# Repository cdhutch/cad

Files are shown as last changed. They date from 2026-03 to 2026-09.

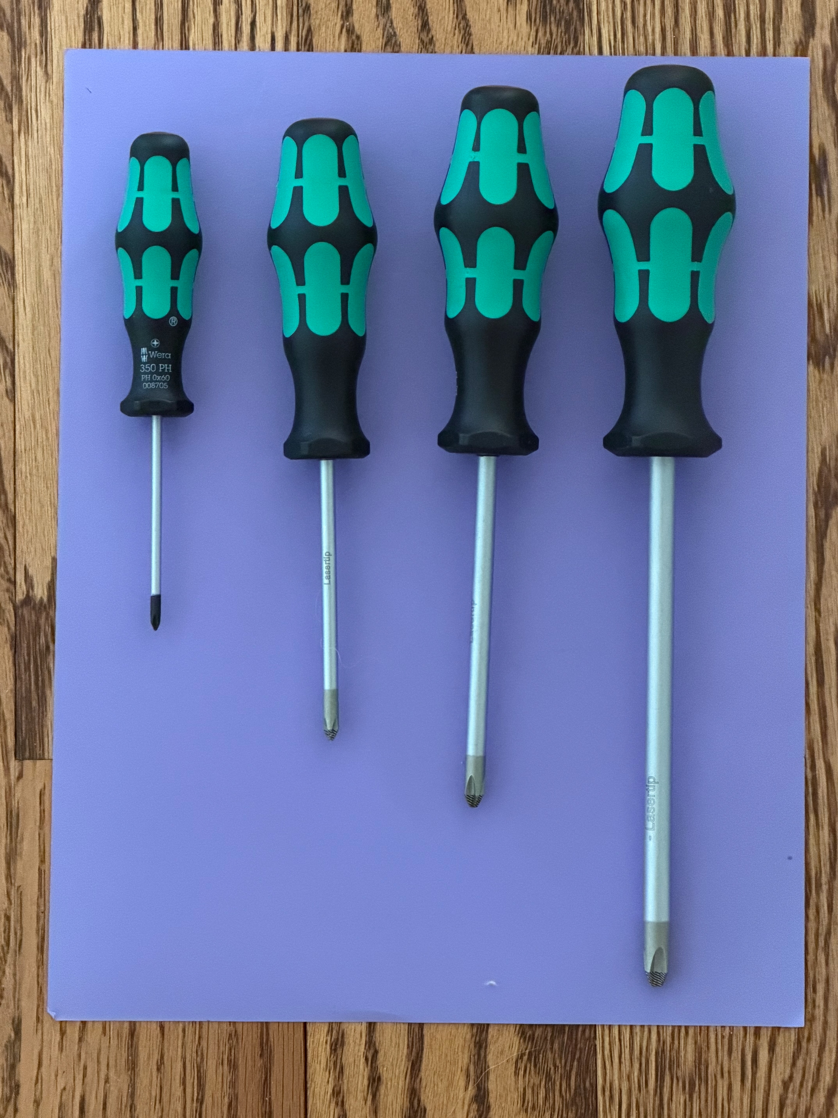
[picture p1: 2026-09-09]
gridfinity/source/tooltrace/wera-phillips-flathead-screwdrivers/photos/phillips.jpeg

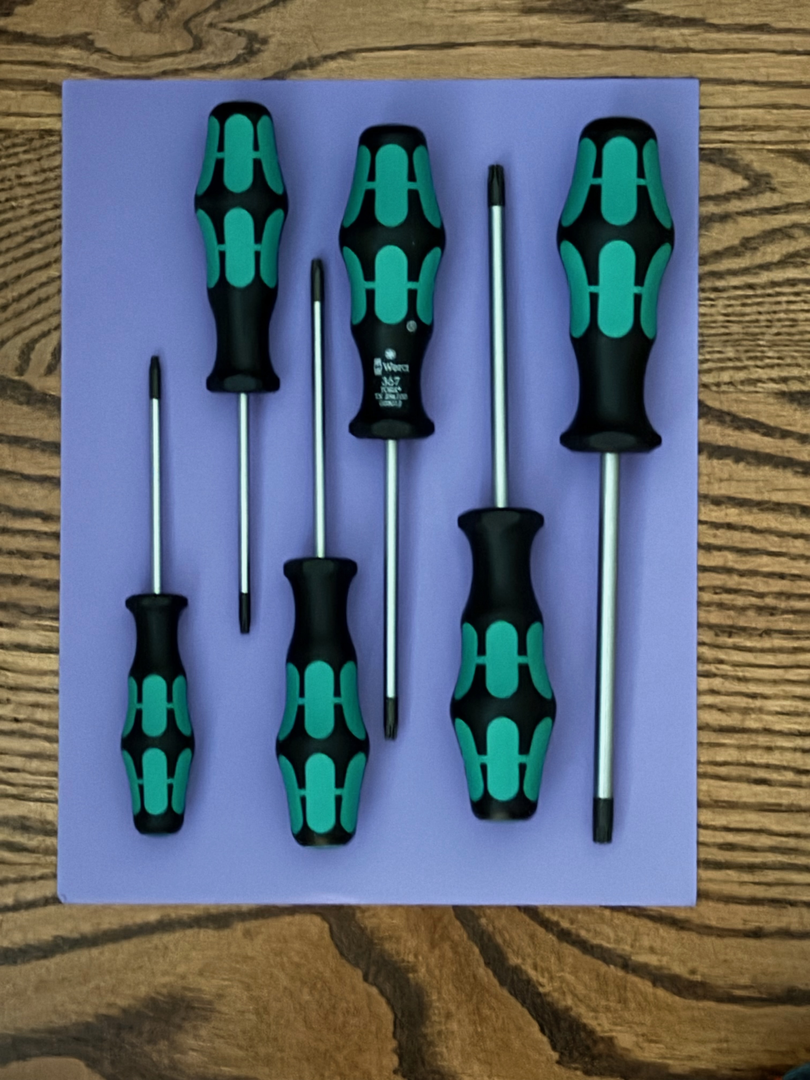
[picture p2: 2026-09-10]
gridfinity/source/tooltrace/wera-367-6-torx/photos/torx.jpeg

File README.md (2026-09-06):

# CAD Library

A general repository for CAD models and 3D-printing assets.

This repository stores parametric design references, exported geometry,
and slicer projects used for prototyping, shop organization, and
hardware builds.

For the fuller working context (active branch, per-project inventory,
step-by-step workflow) see `CLAUDE.md`.

## Design Workflow (summary)

1. **tooltrace.ai** — photograph a tool to extract its 2D/3D profile (STEP + DXF)
2. **Onshape** — import the profile, subtract it from a Gridfinity tray body
3. **Export** — STL for remixing, `.3mf` slicer projects (Bambu Studio) for printing

## Repository Structure

    cad/
    ├── README.md
    ├── CLAUDE.md
    ├── docs/
    │   └── repo-conventions.md
    └── gridfinity/
        ├── README.md
        ├── docs/
        │   ├── naming.md
        │   ├── notes.md
        │   ├── allen-wrench-tray.md
        │   ├── wera-electrical-screwdrivers-tray.md
        │   └── drill_tray_generator.md
        ├── source/
        │   ├── onshape/
        │   │   └── links.md
        │   ├── step/
        │   │   ├── allen-wrenches/
        │   │   └── wera-electrical-screwdrivers/
        │   └── tooltrace/
        │       ├── allen-wrenches/
        │       └── wera-electrical-screwdrivers/
        ├── stl/
        │   ├── baseplates/
        │   │   └── magnet/
        │   └── inserts/
        │       ├── allen-wrenches/
        │       └── wera-electrical-screwdrivers/
        └── 3mf/
            ├── baseplates/
            │   └── magnet/
            ├── grids/
            ├── allen-wrenches/
            ├── nystrom_performance/
            └── wera-electrical-screwdrivers/

## Directory Purpose

### `docs/`

General documentation for the CAD repository: repo conventions, naming
rules, organizational guidance.

### `gridfinity/`

Gridfinity-compatible storage designs and experiments.

#### `source/`

Editable or reference CAD information: Onshape document links, STEP
exports for interoperability, and raw tooltrace.ai exports (STL + DXF)
kept as reference/import material.

#### `stl/`

Printable mesh geometry exported from CAD, split into `baseplates/`
(generic Gridfinity infrastructure) and `inserts/` (tool-specific trays).

#### `3mf/`

Slicer project files (Bambu Studio builds) — plate layouts, supports,
print profiles, often multiple parts per build. Subdirectories organize
prints by role or project, e.g. `baseplates/`, `grids/`, `nystrom_performance/`.

#### `docs/`

Project-specific notes, naming conventions, and per-tool design write-ups.

## File Type Conventions

Preferred formats and naming rules are defined in `docs/repo-conventions.md`
and, for Gridfinity specifics, `gridfinity/docs/naming.md`. In short:
lowercase, hyphenated, version-suffixed filenames; `.3mf`/`.stl`/`.step`/`.stp`/`.dxf`,
all tracked via Git LFS.

## Included Systems

Currently includes:

- Gridfinity storage components (baseplates, grids)
- Drawer organization trays (Nystrom Performance cabinet)
- Custom tool-specific inserts (Allen wrenches, Wera screwdrivers)

Additional CAD projects may be added as new top-level folders alongside
`gridfinity/`, following `docs/repo-conventions.md`.

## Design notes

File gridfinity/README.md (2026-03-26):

# Gridfinity STL Library

Organized Gridfinity-compatible STLs:
- `stl/base/` baseplates/grids/foundations
- `stl/inserts/` tool- and use-specific inserts

See `docs/naming.md` for file naming conventions.

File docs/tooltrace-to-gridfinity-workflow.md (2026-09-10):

# Tool-Specific Gridfinity Tray Workflow (ToolTrace → Gridfinity)

A reproducible, step-by-step guide to building exact-fit tool pockets (Allen
wrenches, screwdrivers, anything with an irregular silhouette).

**Default path: ToolTrace's own native "Gridfinity" export** (Part 1 below)
— trace, lay out, and export STEP/STL directly from ToolTrace, with no CAD
step in between. Use this unless your layout needs something ToolTrace's
manual drag/rotate Layout canvas can't do — namely a **tight interlocking
nest** that packs irregular shapes tighter than simple non-overlapping grid
placement, to minimize wasted Gridfinity squares. For that case, fall back
to the Onshape path (Part 2).

Written up while building the Wera 454/7 HF Set 1 tray
(`gridfinity/docs/wera-454-7-hf-set-1-tray.md`) — that doc has this
project's specific numbers; this doc is the general procedure.

---

## Part 1: ToolTrace-native path (default)

### 1. Photograph the tools

- Shoot on a plain, high-contrast, colored background (cleaner trace than
  paper/white) or on one sheet of Letter/A4 paper with all 4 corners
  visible if you need ToolTrace's paper-based scale calibration instead.
- Multiple tools can share one photo, but every tool must be fully
  separated from the others — no touching/overlapping outlines, and no
  tool touching the edge of the page/background (a trace touching the edge
  can fuse into the background boundary).
- Shoot from further away and zoom in (physically or in-camera) rather than
  filling the frame at close range — reduces lens distortion at the edges
  of the photo, which otherwise skews the traced outline.
- Even, shadow-free lighting — a cast shadow next to the tool can get
  traced as part of its silhouette.
- Include a calibration reference (ruler, checkerboard, or known-size
  object) in frame for ToolTrace's corner-calibration step.
- Export/save as **JPEG or PNG** — ToolTrace's HEIC decoding is unreliable
  server-side ("Failed to convert HEIC file"); convert HEIC photos first.

### 2. Measure/verify tool dimensions independently

Don't rely on the trace alone for critical dimensions — cross-check against
the manufacturer's datasheet and/or physical measurement:
- Watch for spec ambiguity (e.g. Wera's "10.0×200" is the *shaft* length
  only; the handle block adds on top of it — total tool length ≈ shaft +
  handle).
- A single WebFetch of a retailer product page can garble tables (columns
  merging, e.g. a "qty: 1" column bleeding into a size column) — if numbers
  look suspicious, fetch the manufacturer's PDF datasheet directly and
  cross-check.

### 3. Trace each photo in ToolTrace

- One photo = one ToolTrace session/design; there's no multi-photo upload
  into a single session.
- **Mode: Fast vs. Detail** — set this before adding any tool; it cannot be
  changed on a tool after it's added (changing it loses the tool and it
  must be re-added).
  - **Detail mode** segments by apparent contiguous color/material region.
    On a multi-material tool (e.g. matte handle + shiny metal shaft) this
    fragments the tool into multiple disconnected pieces instead of one
    outline.
  - **Fast mode** grabs the whole tool silhouette in a single click. Less
    precise on fine contour detail, but doesn't fragment multi-material
    tools. **Use Fast mode for tools with a handle + metal shaft**
    (T-handles, screwdrivers, etc.).
- Rename the session immediately (the `Name` field) — default names are
  generic/auto-generated and easy to confuse with leftover sessions from
  earlier work.
- Click each tool to trace it, name it, and — critically — **click OK to
  confirm the trace**. A trace that is never confirmed with OK does not
  persist: reopening the design will show the bare photo with no
  AI-selected tool, and the tool will not appear in Import Traces from
  other designs.

### 4. Fix bad traces with Fine Tune

If an exported STEP/STL later comes out looking inverted or corrupted, go
back to the Layout step's **Fine Tune** tool and manually smooth the
offending outline. A hand-traced curve can contain a "sketch singularity"
— a self-intersecting loop or an acute/degenerate point — that blows up
the boolean subtraction used to generate the pocket, producing a solid
tool-shaped plug instead of a recessed pocket. Fine Tune lets you clean up
the outline without re-tracing from scratch.

ToolTrace's Fine Tune UI is good at surfacing exactly where a singularity
is on a given outline — worth checking there proactively (before export)
rather than only reactively after a bad STEP/STL turns up.

### 5. Combine traces from multiple designs with Import Traces

- If your tools are spread across several photos/designs, open the design
  you want to build the final tray in and use **Import Traces** (button
  labeled "Import Tools") to pull in already-traced, OK-confirmed tools
  from your other ToolTrace designs.
- Imported tools show `Source: Imported` in their tool popup (Mode/Enforce
  Symmetry/Angle aren't shown — those only apply at trace time — but
  Pocket Depth remains editable). A generic "Imported" placeholder instead
  of a live thumbnail appears to be cosmetic, not a failed import.
- **Gotchas:**
  - Leftover/stray sessions from past work can appear in the import picker
    under similarly generic auto-generated names — double-check
    thumbnails/dates before selecting, to avoid importing a duplicate.
  - Clicking a tool's **×** in the Tools panel deletes it immediately with
    no confirmation. If this happens by accident, re-import it via Import
    Traces from its original session rather than re-tracing.

### 6. Lay out the tools

- Arrange all tools in the workspace with no overlap. Freshly
  imported/added tools may all appear superimposed at first — drag them
  apart manually.
- ToolTrace's Layout canvas is **manual drag/rotate only** — no auto-nest
  or auto-arrange. It snaps to the grid and shows live size feedback (mm).
  This is fine for "arrange without overlap"; it is **not** the tool for a
  tight interlocking nest that minimizes wasted grid squares — for that,
  use the Onshape path (Part 2) instead.
- Use **Add Simple Shapes → Finger Notch** to add a finger-access scallop
  to any pocket you'll need to pinch a tool out of: a circle with a live,
  draggable diameter. Position it straddling the edge of the pocket. Set
  its depth **deeper than the pocket it's attached to** (retrieval is
  handled by the notch reaching below the tool, not by the pocket itself).
- Other shapes here (Circle, Square, Rectangle, Rounded Rect, Text) are for
  labels/general cutouts, not tool-specific.

### 7. Size and export in the Design step

- **Pocket Depth** (per tool, via each tool's popup) — set individually.
  Rule of thumb: ≈70% of the tool's own handle/crossbar thickness (not the
  hex bit or fastener diameter), leaving ≥2–3mm of base material below the
  pocket floor.
- **Customize Overall Size → Grid Length/Grid Width** — tray footprint in
  Gridfinity grid units (1 unit = 42mm). Pick even numbers so a grid cell
  isn't split across a design boundary — though it would still print fine.
- **Custom Grid Size** — set to **42mm** for standard Gridfinity pitch.
- **Split for Multiple Prints** — subdivides a layout larger than your
  printer's bed into multiple plates, each no larger than a size you
  specify (e.g. 252×252mm = 6×6 units). If a tool's pocket exceeds one
  plate, ToolTrace deliberately splits it across the shared edge of two
  adjacent plates — intentional, not a bug: the pocket halves align once
  the printed plates sit next to each other.
- **Puzzle Piece Mode** (GRIDFINITY panel) — trims empty grid cells so the
  printed outline hugs the tool shapes instead of a full rectangle.
  Separate from, and combinable with, Split for Multiple Prints.
- **Lip Design** (Default/None) and **Base magnets** (None/Corner/Full) —
  standard Gridfinity bin-bottom options.
- **Type must stay "Gridfinity"**, not "Foam" — Foam mode is believed to
  export a solid cutter/tool-shaped body rather than a tray with a
  recessed pocket; check this first if an export ever looks inverted.
- Export **STEP and/or STL**. STEP exports the whole design as one file
  (not split per plate — the plate split is a print-file concept). For a
  split layout, the STL export is a ZIP containing one **tray** STL + one
  **inserts** STL per plate, plus a `manifest.json` with each plate's
  position/size. **Only the tray STL is printed** — load one tray STL per
  plate into Bambu Studio, one print job at a time; the inserts file isn't
  sent to the printer.

### 8. Verify before printing

ToolTrace's own in-browser 3D preview can be unreliable to read — it has
been observed rendering one view for a few seconds and switching to
another, and pocket depths can look visually deceptive (a very deep value
on one tool makes every other tool look shallow by comparison). For a
trustworthy check, load the exported STEP/STL into Bambu Studio (or
Onshape) and inspect it there directly.

### 9. Slice and print

1. Import the STL(s) into Bambu Studio.
2. Use the **"Gridfinity Tray - Light"** process preset
   (`gridfinity/docs/gridfinity-tray-light.json` /
   `gridfinity/docs/bambu-tool-tray-profile.md`) — tuned for low-strength,
   gravity-load-only tool trays: minimal infill, fast print, no brim.
3. Save the sliced **project** as `.3mf` (not "export sliced file" — that
   embeds gcode and bloats the file) →
   `gridfinity/3mf/<project-name>/<descriptive-name>_v<n>.3mf`.
4. Archive source files: STEP/STL/photos under
   `gridfinity/source/tooltrace/<project-name>/` and
   `gridfinity/source/step/<project-name>/` (Git LFS tracks `*.stl`,
   `*.3mf`, `*.step`, `*.stp`, `*.dxf`).
5. Print, test-fit, and update the project doc's Status checklist.

---

## Part 2: Onshape path (fallback / advanced)

Use this instead of Part 1 only when you need a **tight interlocking nest**
that packs irregular tool shapes tighter than simple non-overlapping grid
placement (minimizing total Gridfinity squares consumed across however many
plates are needed), or when ToolTrace's native export produces geometry you
need to hand-repair in real CAD.

**Known reliability risk:** DXF import into Onshape has repeatedly dropped
or corrupted tool geometry on this repo's projects — a tool trace touching
the edge of its source photo/paper gets fused with the page boundary into
one degenerate closed loop that isn't cleanly separable back into a usable
outline (confirmed via DXF entity/geometry analysis with Python `ezdxf`).
This is why the Wera 454/7 HF Set 1 tray was rebuilt on the Part 1 path
after starting here. If you hit this, prefer the STL fallback procedure
below over DXF, or switch to Part 1 entirely if your layout doesn't
actually need interlocking nesting.

### Steps

1. **Trace each photo in ToolTrace** — same as Part 1, steps 1–3, but you
   only need clean individual tool outlines; you don't need to combine,
   lay out, or export a finished design from ToolTrace at all.
2. **Export from ToolTrace: Download → STEP** (also available: SVG, DXF,
   STL, 3MF, PDF).
   - The export contains one solid per tool **plus an auto-generated
     baseplate/background solid** sized to the layout's bounding box —
     discard that extra solid in CAD.
   - Tool solids are thin (~0.5mm) flat "stamp" extrusions — 2D profiles
     meant to be re-extruded to your chosen pocket depth in CAD, not
     pre-cut cavities.
   - Archive the STEP under
     `gridfinity/source/step/<project-name>/<descriptive-name>_v<n>.step`.
3. **Import into Onshape**: new/existing Part Studio → discard the
   auto-generated baseplate solid → clean up each tool profile (trim any
   shadow-elongated edges back to the true silhouette; verify dimensions
   against your independently-measured values from step 2 of Part 1 —
   traced bounding boxes can retain a slight rotation from the source
   photo angle).
4. **Nest** the cleaned profiles at exact coordinates, respecting your
   printer's practical build-plate cap in Gridfinity units (e.g. a
   256mm-cube printer → 6×6 grid units = 252×252mm per plate). Group tools
   into multiple plates if needed and note the split.
5. **Extrude** a Gridfinity tray body per plate and **boolean-subtract**
   the tool pockets + finger notches.
6. Apply the **standard Gridfinity bin-bottom interface** (lip, 42mm grid,
   optional magnet pockets) — use the repo's usual approach (custom
   feature or generator) rather than hand-modeling it.
7. **Export STL** per plate → `gridfinity/stl/inserts/<project-name>/`.
8. Record the Onshape document link in `gridfinity/source/onshape/links.md`.
9. Slice and print — same as Part 1, step 9.

### STEP import can hang forever — STL fallback procedure

STEP import into Onshape can get stuck at **"Post-processing..."**
indefinitely (not just slow) for a given file — confirmed by two separate
full-import attempts (default "Import to this document" mode, then
"Combine to a single Part Studio" mode) that both stalled identically for
10+ minutes, with Onshape's own status page showing "All Systems
Operational" at the time. If a STEP import is still stuck after several
minutes, cancel and fall back to STL:

1. **Export STL instead of STEP** from ToolTrace (Download → STL). This
   zips **one file per solid body** (`body_1.stl`, `body_2.stl`, ... one
   per tool, plus one for the auto-generated baseplate). Discard the
   baseplate STL (largest file by far).
2. **Upload all the tool STLs to Onshape in one batch** (drag/drop or the
   file picker takes multiple files at once).
3. In the **Units** dropdown of the import dialog, change it to
   **Millimeter** — Onshape's STL importer defaults to Inch, so ToolTrace's
   mm-based exports come in 25.4× oversized otherwise. (Shortcut: focus the
   dropdown and press "m" twice — first press selects Meter, second
   cycles to Millimeter.) Leave "Create a composite part when importing
   multiple or non-solid bodies" unchecked if you want each tool as an
   independently-positionable part later.
4. Unlike STEP import, the STL import dialog has no "combine to a single
   Part Studio" option — each STL becomes its own Part Studio tab, plus one
   extra raw "CAD Imports" tab. Consolidate them yourself (next step).
5. **Consolidate into one working Part Studio using the "Derived" feature**
   (Search Tools → "derive", not on the default toolbar): in your target
   Part Studio, Search Tools → Derived → "Select Part Studio..." → pick a
   source tab → confirm. Repeat once per source tab.
   - **Copy/paste of parts between Part Studio tabs is unreliable** in this
     workflow — use Derived instead.
   - On a Mac, use **Cmd+click** (not Ctrl+click, not Shift+click) for
     additive multi-select in a feature/parts tree — Ctrl+click triggers
     macOS's native right-click instead.
6. **A body can import as open Surfaces instead of a solid Part** — a real
   mesh defect (missing wall/side geometry), not a cosmetic glitch. Onshape
   has no "Stitch" feature; the closest equivalent, Boolean Union, can't
   bridge an actual gap between disconnected surface patches (it reports
   "Boolean resulted in no geometry change" on a genuinely gapped pair).
   - **Diagnose first**: view the *original* (pre-Derived) Part Studio for
     that body from an orthographic side view. If it renders as a
     razor-thin line with no visible depth, the STL never had real wall
     geometry in that direction — don't hand-patch it; re-trace/re-export
     that one tool from ToolTrace instead, or rebuild it manually from its
     2D outline plus known real-world dimensions.

---

## Lessons learned (things that went wrong or wasted time)

General (apply to either path):
- Don't assume a retailer product page's parsed dimensions are correct —
  cross-check against the manufacturer's own PDF datasheet.
- Don't assume a "shaft length" spec is the tool's total length — check
  whether the handle/grip adds to it.
- HEIC photos will silently fail server-side in ToolTrace — convert first.
- A trace that's never confirmed with OK doesn't persist, and won't show
  up later in Import Traces — always click OK.
- A sketch singularity (self-intersecting loop) in a hand-traced outline
  can corrupt the boolean subtraction and invert the export — use Fine
  Tune to clean it up rather than re-tracing from scratch.
- Detail mode fragments multi-material tools (matte handle + shiny metal
  shaft) into disconnected pieces — use Fast mode for those.

Onshape path only:
- DXF import into Onshape has repeatedly dropped/fused tool geometry on
  this repo's projects, especially when a trace touches the source
  photo/paper edge — prefer the STL fallback over DXF, or use the
  ToolTrace-native path (Part 1) if your layout doesn't need interlocking
  nesting.
- ToolTrace has no bin-packing/auto-nest solver — don't try to get a tight
  interlocking layout by dragging in its Layout canvas; that's what
  Onshape nesting is for.
- A combined multi-body STEP import into Onshape can hang at
  "Post-processing..." forever, not just slowly — if stuck more than a few
  minutes with no Onshape outage reported, stop waiting and fall back to
  STL.
- Onshape's STL importer defaults Units to Inch, not Millimeter — always
  check/change this before importing a ToolTrace STL (mm) or everything
  comes in 25.4× oversized.
- Copy/paste of parts between Part Studio tabs is unreliable — use the
  Derived feature to consolidate multiple Part-Studio imports instead.
- On a Mac, use Cmd+click (not Ctrl+click, not Shift+click) for additive
  multi-select in Onshape's feature/parts tree.
- Onshape has no "Stitch" feature — a side-by-side orthographic view
  showing no real depth at all means the source mesh is missing geometry
  that can't be patched by hand; re-trace/re-export that tool instead.

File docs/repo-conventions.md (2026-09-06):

# CAD Repo Conventions

## Structure
- Each major project gets its own top-level folder (see `CLAUDE.md` → "Adding New Projects").
- Within a project:
  - `source/` contains editable or exchange CAD sources (e.g. Onshape links, STEP imports, tooltrace exports)
  - `stl/` contains printable/exported mesh geometry
  - `3mf/` contains slicer/project/build files
  - `docs/` contains project-specific notes and naming conventions

Within `stl/` and `3mf/`, split by role first (e.g. `baseplates/`, `grids/`, `inserts/`),
then by tool/part underneath — keep that split consistent between `stl/` and `3mf/`
rather than nesting extra nearly-synonymous folders (e.g. avoid `stl/base/baseplates/`;
use `stl/baseplates/` directly, matching `3mf/baseplates/`).

## Naming
- Prefer lowercase
- Use hyphens for free-text descriptors
- Include version suffixes such as `_v1`, `_v2`
- Use semantic folders before long filenames where practical
- Full pattern and Gridfinity-specific details: `gridfinity/docs/naming.md`

## File Types
- `.3mf` for slicer/build projects
- `.stl` for mesh exports
- `.step` / `.stp` for exchange geometry
- `.dxf` for 2D trace/sketch reference geometry (tooltrace exports)

All of the above are tracked via Git LFS — see the repo's `.gitattributes`.

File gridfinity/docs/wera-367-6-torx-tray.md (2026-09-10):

# Wera 367/6 TORX Screwdriver Tray — Design Notes

Gridfinity tray for the Wera 367/6 TORX Kraftform Plus set (6 T-handle-less
straight Torx screwdrivers). Built with ToolTrace.ai's native "Gridfinity"
export mode — see `docs/tooltrace-to-gridfinity-workflow.md` (Part 1) for
the general, reusable procedure this project follows.

---

## Tool set

Per Wera's catalog (part 05028062001, plain 367/6 — **not** the HF
"holding function" variant, 05028059001, which has a 7th TX8×60mm tool and
different sizing on a couple of the others). Confirm against your physical
set before relying on this table:

| Tool | Tip size | Shaft length | Handle Ø | Pocket depth | Finger notch depth |
|---|---|---|---|---|---|
| Wera 367 | TX 10 | 80 mm | 25 mm | 17.5 mm | 28.0 mm |
| Wera 367 | TX 15 | 80 mm | 32 mm | 22.5 mm | 28.0 mm |
| Wera 367 | TX 20 | 100 mm | 32 mm | 22.5 mm | 28.0 mm |
| Wera 367 | TX 25 | 100 mm | 36 mm | 25.0 mm | 28.0 mm |
| Wera 367 | TX 30 | 115 mm | 36 mm | 25.0 mm | 28.0 mm |
| Wera 367 | TX 40 | 140 mm | 40 mm | 28.0 mm | 28.0 mm |

- **Handle Ø** — measured by Craig with calipers (thickest point of the
  Kraftform grip, not the shaft/tip diameter).
- **Pocket depth** — handle Ø × 70% rule, same as the prior two trays,
  rounded to the nearest 0.5mm.
- **Finger notch depth** — expected to land at **28.0mm for all 6 tools**
  (matching the deepest pocket, TX 40), based on how the notch-depth
  constraint behaved on the flathead+Phillips tray (notch must be no
  lower than the deepest pocket, and the design's max achievable depth
  turned out to equal that same value, leaving no margin above it) — but
  confirm this holds once you're in ToolTrace, since it's an observed
  pattern, not a documented API guarantee.

### Source photos → ToolTrace design

All 6 tools traced from a single photo, `torx.jpeg` (all 6 on one sheet).

### Layout

All 6 tools arranged on a **7u × 9u** grid (42mm pitch), split into
**4 plates** (2×2), each plate **147 × 189mm** (3.5u × 4.5u — a
non-integer split, same pattern seen on the prior two trays; the split
seams won't land exactly on 42mm grid lines).

ToolTrace's internal design name is "Green Handled Screwdrivers" (from the
split-STL `manifest.json`) — same naming quirk as the prior two jobs
("6.0x150", "Green Screwdrivers"); it's not a dimension, just whatever the
design happened to be named at export time.

### Exports

- `gridfinity/source/tooltrace/wera-367-6-torx/split-stl/` — 4 plates ×
  {tray, inserts} STL pairs, plus `manifest.json`.
- `gridfinity/source/step/wera-367-6-torx/wera-367-6-torx-tray_v1.step`
  — STEP export of the whole combined design (not split per plate).
- `gridfinity/stl/inserts/wera-367-6-torx/` — the 4 tray STLs, archived
  and renamed per `naming.md`. Note: each tray's actual bounding box
  (measured directly from the STL) is noticeably smaller than the
  manifest's nominal 147×189mm tile size — tools don't fill their whole
  reserved tile, so the real per-plate footprints are ~2.5×4.5u for
  pieces 1/2/4 and ~2.5×1.5u for piece 3 (which has fewer/smaller tools).
  Total height 39.17mm (5.6u) matches the flathead+Phillips tray exactly,
  since both designs share the same 28.0mm deepest pocket.
- `gridfinity/3mf/wera-367-6-torx/wera-367-6-torx-tray_7x9x5.6u_v1.3mf`
  — sliced Bambu Studio project (all 4 plates).

---

## Status

- [x] Tool set confirmed against physical set — Craig's 6 handle
      measurements (T10/T15/T20/T25/T30/T40) match the plain 367/6 set,
      not the 7-piece HF variant
- [x] Tools photographed (colored background, distance + zoom, shadow-free)
- [x] Tools traced in ToolTrace (Fast mode)
- [x] Laid out on a 7u × 9u grid, no overlap
- [x] Pocket depths set per tool (70%-of-handle-Ø rule)
- [x] Finger notches added per tool (28.0mm depth, matching deepest pocket)
- [x] Sketch singularity found (via ToolTrace's Fine Tune UI) and fixed on
      one tool shape
- [x] STEP/STL exported; print came out well (per Craig, 2026-09-10)
- [x] Source photo (`torx.jpeg`), STEP export, and raw split-STL exports
      copied into repo
- [x] Tray STL archived to `gridfinity/stl/inserts/wera-367-6-torx/`
      (4 pieces, renamed per naming convention)
- [x] Printed (per Craig, 2026-09-10)
- [x] Sliced `.3mf` saved to `gridfinity/3mf/wera-367-6-torx/`

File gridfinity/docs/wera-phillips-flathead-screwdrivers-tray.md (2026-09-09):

# Wera Flathead + Phillips Screwdriver Tray — Design Notes

Gridfinity tray for 7 Wera precision screwdrivers — 3 slotted (flathead) and
4 Phillips — built as **one combined ToolTrace design**, split into 3 print
plates. Follows the ToolTrace-native workflow in
`docs/tooltrace-to-gridfinity-workflow.md` (Part 1).

Only the 3 tray plates were printed — the color-coded insert plan
(printing each plate's insert sheet twice, once per color, and hand-sorting
pieces by tool-head shape) was dropped as unnecessary complexity, and also
ran into a real export issue: each `*-inserts.stl` bundles its tool-shaped
plugs as one mesh with every plug still at its *actual* pocket depth
(so a 17.5mm plug and a 28.0mm plug sit at different heights in the same
file), rather than reset to sit flat on a print bed — printing them would
have required splitting the mesh into individual objects and dropping each
to the bed separately in Bambu Studio. Not worth it: the trays are usable
without the inserts, so they were dropped rather than fixed.

---

## Tool set

| Tool | Blade/head spec | Shaft length | Handle Ø | Pocket depth |
|---|---|---|---|---|
| Wera 335 | 0.5 × 3.0 mm slotted | TBD | 25 mm | 17.5 mm |
| Wera 334 | 0.8 × 5.0 mm slotted | 100 mm | 30 mm | 21.0 mm |
| Wera 334 | 1.2 × 6.5 mm slotted¹ | 150 mm | 36 mm | 25.0 mm |
| Wera 350 | PH 0 | 60 mm | 25 mm | 17.5 mm |
| Wera 350 | PH 1 | 80 mm | 32 mm | 22.5 mm |
| Wera 350 | PH 2 | 100 mm | 36 mm | 25.0 mm |
| Wera 350 | PH 3 | 150 mm | 40 mm | 28.0 mm |

¹ Originally listed as 1.2×5×150; corrected to 1.2×6.5×150 to match both
Craig's own handle measurement and Wera's official catalog variant
(part 05110010001).

- **Handle Ø** — measured by Craig with calipers (thickest point of the
  Kraftform grip, not the shaft/blade diameter — Wera's own spec sheets
  only publish the latter, which is far too small to be useful for pocket
  depth).
- **Pocket depth** — handle Ø × 70% rule, same as the Wera 454/7 tray,
  rounded to the nearest 0.5mm.
- **Finger notch depth: 28.0mm for all 7 tools** (not a per-tool value).
  ToolTrace enforces notch depth ≥ the deepest pocket in the design (28.0mm,
  the PH 3) *and* ≤ the same 28.0mm ceiling — so 28.0mm is the only value
  that satisfies both constraints, with no margin available above it.
- **Finger notch placement**: centered on the *end (tip) of the handle* for
  every tool, wrapping around the rounded end on three sides — not on the
  blade (too narrow to grip, and risks bending/scratching it) and not on
  the side of the handle (only exposes one flat edge, less useful for a
  pinch-and-lift than the rounded tip).

### Reference: Wera catalog specs

From Wera's own product pages (blade diameter here is the shaft, not the
handle — see note above):

| Tool | Blade Ø (shaft) | Handle length | Part number |
|---|---|---|---|
| Wera 334, 0.8×5.0×100 | 5.0 mm | 98 mm | 05007610001 |
| Wera 334, 1.2×6.5×150 | 6.0 mm | 105 mm | 05110010001 |
| Wera 350 PH 0×60 | 3.0 mm | 81 mm | 05008705001 |
| Wera 350 PH 1×80 | 4.5 mm | 98 mm | 05008710001 |
| Wera 350 PH 2×100 | 6.0 mm | 105 mm | 05008720001 |
| Wera 350 PH 3×150 | 8.0 mm | 112 mm | 05008735001 |

(Wera 335 0.5×3.0 not confirmed against an exact catalog row.)

### Source photos → ToolTrace design

| Photo | Tools traced |
|---|---|
| `flathead.jpeg` | Wera 335, Wera 334×100, Wera 334×150 (all 3, one photo) |
| `phillips.jpeg` | Wera 350 PH0, PH1, PH2, PH3 (all 4, one photo) |

Both photos traced into the same ToolTrace session (no Import Traces
needed — unlike the 454/7 job, all 7 tools ended up together directly).

### Layout

All 7 tools arranged on a **13u × 3u** grid (42mm pitch), split into
**3 plates**. ToolTrace's internal design name is "Green Screwdrivers"
(shows up in the split-STL `manifest.json`) even though the exported
files are prefixed `wera-phillips-flathead-*` — a naming quirk like the
454/7 job's "6.0x150" collection name; ignore it, it's not a dimension or
a hint about anything other than what the design happened to be named at
some point.

Each plate measures **182.04 × 126.03mm** (≈4.33u × 3u) — note this is
**not** a whole-number grid split (13 ÷ 3 = 4.33), unlike the 454/7 job's
plates, which were whole units (5u/4u). Worth knowing if these trays are
meant to dock into a shared Gridfinity baseplate layout later — the split
seams won't land exactly on 42mm grid lines. Craig reviewed the STEP/STL
in Bambu Studio and confirmed everything looks correct as exported, so
this is a documentation note rather than a problem to fix.

Tools are interleaved across the 3 plates rather than grouped by type, so
plate boundaries don't separate flathead from Phillips — color-coding
happens at the insert level instead (see Exports below), not per-plate.

### Exports

- `gridfinity/source/tooltrace/wera-phillips-flathead-screwdrivers/photos/`
  — `flathead.jpeg`, `phillips.jpeg`.
- `gridfinity/source/tooltrace/wera-phillips-flathead-screwdrivers/split-stl/`
  — 3 plates × {tray, inserts} STL pairs, plus `manifest.json`.
- `gridfinity/source/step/wera-phillips-flathead-screwdrivers/wera-phillips-flathead-screwdrivers-tray_v1.step`
  — STEP export of the whole combined design (not split per plate).

**Print plan actually used:** only the 3 `*-tray.stl` files were printed,
one plate at a time, single color. The `*-inserts.stl` files (kept in the
repo for reference) were not printed — see the note above.

---

## Status

- [x] All 7 tools photographed (2 photos: flathead.jpeg, phillips.jpeg)
- [x] All 7 tools traced in ToolTrace (Fast mode)
- [x] Laid out on a 13u × 3u grid, no overlap
- [x] Pocket depths set per tool (70%-of-handle-Ø rule)
- [x] Finger notches added per tool (28.0mm depth, handle-tip placement)
- [x] Split for Multiple Prints configured (3 plates)
- [x] STEP/STL exported and verified in Bambu Studio
- [x] Source photos, split-STL exports, and STEP copied into repo
- [x] Trays sliced and printed (all 3 plates, single color, no inserts)
- [x] Sliced `.3mf` saved to
      `gridfinity/3mf/wera-phillips-flathead-screwdrivers/wera-phillips-flathead-tray_4.33x3x5.6u_v1.3mf`
      (all 3 plates in one project file)
- [x] Tray STL archived to
      `gridfinity/stl/inserts/wera-phillips-flathead-screwdrivers/`
      (`..._piece1-of-3_v1.stl` through `..._piece3-of-3_v1.stl`)
- [x] Color-coded insert plan dropped (see note above)

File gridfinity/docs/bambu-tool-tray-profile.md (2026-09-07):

# Bambu Studio Print Profile: Gridfinity Tray - Light

A custom Bambu Studio process preset for **static tool trays** — printed on a
Bambu Lab P2S — that minimizes filament and print time. These trays only hold
tools by gravity (no clamping, no structural load beyond a tool resting in a
pocket), so wall count, infill, and supports can all be cut well below a
normal-quality default.

Verified 2026-09-06: created in Bambu Studio's Process panel, checked field-by-field
in the UI, exported, and confirmed to match. This replaces an earlier draft of this
doc/profile that had two real problems — its markdown table claimed a 1.2mm wall
while the JSON set a single 0.42mm-line-width wall loop (an unreconciled
inconsistency), and it enabled tree supports by default even though these tray
shapes are normally self-supporting. Both are fixed below.

## Settings

Preset name: **"Gridfinity Tray - Light"**, inherits from **"0.24mm Standard @BBL P2S"**
(all quality/speed/temperature settings come from that base preset, unchanged —
only the fields below are overridden):

| Setting | Value | Rationale |
|---|---|---|
| Wall loops | 2 | Matches the "0.24mm Standard" base already — 1 wall risks pinholes/fragile corners at low infill |
| Top shell layers | 2 | Enough to bridge sparse infill without holes; nothing presses on the surface |
| Bottom shell layers | 2 | Same — no load-bearing requirement |
| Sparse infill density | 8% | Just holds gravity-fed contents; far below a normal 15% default |
| Sparse infill pattern | Lightning | Purpose-built for "support the top surface, nothing else" — uses less material than any other pattern at a given density |
| Supports | Off | Tooltrace-derived tray pockets are normally flat-bottomed and self-supporting; check the slice preview per-model rather than defaulting supports on |
| Brim type | No brim | Tray footprints are normally large enough for bed adhesion without one |
| Layer height | 0.24mm (inherited) | Largest built-in preset for this printer/nozzle; cuts print time without hand-tuning speeds |

Everything not listed above (speeds, temperatures, cooling, retraction) is left
exactly as Bambu's own "0.24mm Standard @BBL P2S" preset has it — those are
already tuned for this printer, so there's no reason to guess at replacement
numbers.

## When to Use This Profile

✅ Static tool storage trays (hand tools, drill bits, etc.)
✅ Gridfinity-compatible inserts, gravity-fed only
✅ Drawer organizers

❌ Anything that needs to resist lateral force, clamping, or repeated stress
❌ Parts with real overhangs — check the slice preview; if it needs supports, this profile doesn't turn them on for you

## How to Import

1. Bambu Studio → File → Import → Import Configs (or the import icon near the
   preset dropdown)
2. Select `gridfinity-tray-light.json`
3. Confirm it appears in the Process dropdown as "Gridfinity Tray - Light"

To reproduce it by hand instead: start from "0.24mm Standard @BBL P2S" and change
only the fields in the Settings table above (wall loops, infill, top/bottom
shells, supports, brim — under the Strength / Support / Others tabs respectively).

## Notes

- This is PLA-tuned by inheritance from the base preset; if you switch materials,
  Bambu Studio's own material presets should still take precedence for temps.
- No filament-savings percentage is claimed here — the earlier draft's "45-55%
  savings" table was a guess, not a measurement. If you want a real number, compare
  the sliced filament estimate for the same model under this preset vs. "0.24mm
  Standard @BBL P2S" unmodified.

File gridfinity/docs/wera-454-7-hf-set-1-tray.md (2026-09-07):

# Wera 454/7 HF Set 1 Hex Driver Tray — Design Notes

Gridfinity tray for the Wera 454/7 HF Set 1 (7-piece T-handle Hex-Plus hex
driver set: 2.5, 3, 4, 5, 6, 8, 10 mm). Built entirely with **ToolTrace.ai's
native "Gridfinity" export mode** — trace, lay out, and export STEP/STL
directly from ToolTrace, with no DXF import or Onshape boolean-subtract step.

This supersedes the DXF → Onshape workflow used for earlier trays (see
`wera-electrical-screwdrivers-tray.md`, `allen-wrench-tray.md`). That route
was abandoned for this job after repeated DXF-import failures — see
"Why not the Onshape DXF/STEP route" below.

---

## General Process: ToolTrace's native Gridfinity workflow

This section is written to be reproducible for the next tool set.

### 1. Photograph the tools

- One photo can hold multiple tools, but every tool in it must be fully
  separated from the others — no touching or overlapping outlines, and no
  tool touching the edge of the page/background (ToolTrace's trace can fuse
  a tool outline into the background boundary if it touches the edge).
- Shoot on a plain, high-contrast, colored background — this makes the trace
  outline much cleaner than a paper/white background.
- Shoot from further away and zoom in (physically or in-camera), rather than
  filling the frame at close range — this reduces lens distortion at the
  edges of the photo, which otherwise skews the traced outline.
- Avoid shadows — flat, even lighting so no shadow edge gets picked up as
  part of the tool outline.
- Include a calibration reference (ruler, checkerboard, or known-size object)
  in frame for ToolTrace's corner-calibration step.

### 2. Create one ToolTrace design per photo

- ToolTrace's upload does not accept iPhone HEIC photos ("Failed to convert
  HEIC file") — convert to JPEG first.
- Upload the photo, run corner calibration against the reference object so
  ToolTrace knows real-world scale.
- **Mode: Fast vs. Detail** — set this before adding any tool; it cannot be
  changed on a tool after it's added (changing it loses the tool and it must
  be re-added).
  - **Detail mode** segments by apparent contiguous color/material region.
    On a multi-material tool (e.g., matte handle + shiny metal shaft) this
    fragments the tool into multiple disconnected pieces instead of one
    outline.
  - **Fast mode** grabs the whole tool silhouette in a single click. Less
    precise on fine contour detail, but doesn't fragment multi-material
    tools. **Use Fast mode for tools with a handle + metal shaft
    (T-handles, screwdrivers, etc.).**
- Click each tool to trace it, name it, and — critically — **click OK to
  confirm the trace**. A trace that is never confirmed with OK does not
  persist: reopening the design will show the bare photo with no
  AI-selected tool, and the tool will not appear in "Import Traces" from
  other designs. (This bit us on the 8 mm tool — it looked done in the
  session but had never been confirmed, so the design came back empty.)

### 3. Fix any bad traces with Fine Tune

- If an exported STEP/STL later comes out looking inverted or corrupted
  (see the "singularity" issue below), go back to the Layout step's **Fine
  Tune** tool and manually smooth the offending outline. A hand-traced
  curve can contain a "sketch singularity" — a self-intersecting loop or an
  acute/degenerate point — that blows up the boolean subtraction used to
  generate the pocket, producing a solid tool-shaped plug instead of a
  recessed pocket. Fine Tune lets you clean up the outline without
  re-tracing from scratch.

### 4. Combine tools from multiple designs with Import Traces

- If your tools are spread across several photos/designs (because some
  tools share a photo and some don't), open the design you want to build
  the final tray in and use **Import Traces** (button labeled "Import
  Tools") to pull in already-traced, OK-confirmed tools from your other
  ToolTrace designs.
- Imported tools show `Source: Imported` in their tool popup. Their
  Mode/Enforce Symmetry/Angle fields aren't shown (those only apply at
  trace time), but Pocket Depth remains editable per tool.
- An imported tool may show a generic "Imported" placeholder instead of a
  live thumbnail in the tool list — this appears to be cosmetic, not a sign
  the import failed.
- Rename each per-photo session immediately after tracing (ToolTrace's
  auto-generated names are generic and easy to confuse later). Stray or
  leftover sessions from earlier attempts can linger in the Import Traces
  picker under similarly generic names.
- Clicking a tool's delete "×" in the Tools panel removes it immediately
  with no confirmation dialog. If this happens by accident, re-import the
  tool via Import Traces from its original session rather than re-tracing.

### 5. Lay out the tools

- In the Layout step, arrange all tools in the workspace with no overlap.
  Freshly imported/added tools may all appear superimposed at first — drag
  them apart manually.
- Use **Add Simple Shapes → Finger Notch** to add a finger-access scallop to
  any pocket you'll need to pinch a tool out of: it's a circle with a live,
  draggable diameter. Position it straddling the edge of the pocket. Set its
  depth **deeper than the pocket it's attached to** (retrieval is handled by
  the notch reaching below the tool, not by the pocket itself), and deeper
  than every pocket in the layout if it's a shared/central notch.
- Other shapes available here (Circle, Square, Rectangle, Rounded Rect,
  Text) are for labels or general cutouts, not tool-specific.

### 6. Size and export in the Design step

Useful controls in the Design/SIZE/GRIDFINITY panels:

- **Pocket Depth** (per tool, via each tool's popup) — set individually for
  each tool; see the job-specific pocket-depth table below for the rule of
  thumb used.
- **Customize Overall Size → Grid Length / Grid Width** — sets the tray's
  footprint in Gridfinity grid units (1 unit = 42 mm standard pitch). Pick
  even numbers so a grid cell isn't split across a design boundary — though
  in theory a split cell would still print fine with additive manufacturing.
- **Custom Grid Size** — set to **42 mm** for standard Gridfinity pitch.
- **Split for Multiple Prints** — subdivides a layout larger than your
  printer's bed into multiple plates, each no larger than a size you
  specify (e.g. 252×252 mm = a 6×6 unit plate). If a single tool's pocket
  is bigger than one plate, ToolTrace deliberately splits that pocket
  across the shared edge of two adjacent plates — this is intentional, not
  a bug: the pocket halves align once the printed plates are placed next
  to each other.
- **Puzzle Piece Mode** (GRIDFINITY panel) — trims away empty grid cells so
  the printed outline hugs the tool shapes instead of staying a full
  rectangle. This is a separate feature from Split for Multiple Prints and
  can be combined with it.
- **Lip Design** (Default/None) and **Base magnets** (None/Corner/Full) —
  standard Gridfinity bin-bottom options.
- **Type: must stay "Gridfinity"**, not "Foam." Foam mode is believed to
  export a solid cutter/tool-shaped body rather than a tray with a
  recessed pocket — if an export ever looks inverted, check this first.
- Export **STEP and/or STL** directly from this step. For a "Split for
  Multiple Prints" layout, ToolTrace's STL export is a ZIP containing one
  **tray** STL + one **inserts** STL per piece, plus a `manifest.json`
  describing each piece's plate position/size. **Only the tray file is
  printed** — in Bambu Studio, load and print one tray STL per plate, one
  print job at a time; the inserts file is not sent to the printer.

### 7. Verify before printing

ToolTrace's own in-browser 3D preview can be unreliable to read — it has
been observed rendering one view for a few seconds and then switching to a
different view, and pocket depths can look visually deceptive (a very deep
value on one tool makes every other tool look shallow by comparison). For a
trustworthy check, load the exported STEP/STL into Bambu Studio (or
Onshape) and inspect it there directly.

### 8. Slice and print

Slice the tray STL in Bambu Studio, save as `.3mf` into
`gridfinity/3mf/<tool-name>/` per repo convention, and print.

### Why not the Onshape DXF/STEP route

Earlier trays in this repo used ToolTrace → DXF export → Onshape import →
manual boolean-subtract of the tool outline from a Gridfinity tray body.
For this job, DXF import into Onshape repeatedly dropped or corrupted tool
geometry — DXF analysis (via Python `ezdxf`) confirmed that a tool trace
touching the edge of the source photo/paper gets fused with the page
boundary into a single degenerate closed loop, which isn't cleanly
separable back into a usable tool outline. ToolTrace's native Gridfinity
export mode does the trace-to-pocket boolean work internally and skips the
DXF/Onshape round trip entirely, so this job was rebuilt on that path.

---

## Job-Specific: Wera 454/7 HF Set 1

### Tool set

7-piece T-handle Hex-Plus hex driver set. All per-tool data points in one
place:

| Hex size | Shaft length (catalog spec) | Total length (shaft + handle) | Handle block length | Shaft dia. (≈hex×1.2) | T-handle crossbar length | Crossbar thickness (used for pocket calc) | Pocket depth used | Finger notch depth |
|---|---|---|---|---|---|---|---|---|
| 2.5 mm | 100 mm | 132.0 mm | 32.0 mm | 3.0 mm  | 77.0 mm  | 15 mm | 10.5 mm | TBD¹ |
| 3 mm | 100 mm | 133.1 mm | 33.1 mm | 3.6 mm  | 79.9 mm  | 19 mm | 13.5 mm | TBD¹ |
| 4 mm | 100 mm | 135.2 mm | 35.2 mm | 4.8 mm  | 85.6 mm  | 19 mm | 13.5 mm | TBD¹ |
| 5 mm | 150 mm | 187.3 mm | 37.3 mm | 6.0 mm  | 91.3 mm  | 22 mm | 15.5 mm | TBD¹ |
| 6 mm | 150 mm | 189.5 mm | 39.5 mm | 7.2 mm  | 97.1 mm  | 22 mm | 15.5 mm | TBD¹ |
| 8 mm | 200 mm | 243.7 mm | 43.7 mm | 9.6 mm  | 108.5 mm | 22 mm | 15.5 mm | TBD¹ |
| 10 mm  | 200 mm | 248.0 mm | 48.0 mm | 12.0 mm | 120.0 mm | 23 mm | 16.0 mm | TBD¹ |

Column notes:
- **Shaft length / total length / handle block length / shaft dia. / T-handle
  crossbar length** — from Wera's official datasheet, captured earlier in
  this project as a cross-check against the traced/photographed geometry.
  The shaft-length spec (e.g. "10.0×200") is the shaft only — total length
  ≈ shaft + handle, not the shaft-length spec alone.
- **Crossbar thickness** — Craig's own measurement of the T-handle
  crossbar's thickness/diameter (not its length — that's the separate
  "T-handle crossbar length" column above, and the two shouldn't be
  confused). This is the dimension the pocket depth is calculated from.
- **Pocket depth used** — the value actually set in ToolTrace, per tool:
  crossbar thickness × 70%, leaving at least 2–3 mm of base material below
  the pocket floor.
- **Finger notch depth** — ¹TBD: one finger notch was added per tool
  pocket in the Layout step, and each notch's depth must exceed the pocket
  it serves; the deepest pocket in the layout is 16.0 mm (10 mm tool), so
  every notch depth used was at least that. The exact per-tool values
  Craig set in ToolTrace were not recorded in this session — fill in once
  known, along with total print height and base thickness (see Status).

Wera catalog shaft lengths (used as ground truth over photo-based
measurement) match the table above.

### Source photos → ToolTrace designs

| Photo | Tools traced |
|---|---|
| `10mm.jpeg` | 10 mm |
| `8mm.jpeg` | 8 mm |
| `6mm.jpeg` | 6 mm |
| `5mm.jpeg` | 5 mm |
| `small.jpeg` | 4 mm, 3 mm, 2.5 mm (all three, traced together in Fast mode) |

All 7 tools were traced in **Fast mode** — Detail mode fragmented these
tools into disconnected pieces (matte handle vs. shiny metal shaft) and was
abandoned early on. The 10 mm, 6 mm, and 5 mm designs held their tools
directly; the 8 mm, 4 mm, 3 mm, and 2.5 mm tools were imported into the
combined layout via **Import Traces** from their respective designs.

### Layout

All 7 tools arranged by hand on a **9u × 11u** grid (42 mm pitch). Split
for Multiple Prints enabled at a **252 × 252 mm** (6×6 unit) max plate size
— the limit of the target printer's bed — producing **4 plates**. Where a
tool's pocket exceeded one plate, ToolTrace split it across the shared edge
of two adjacent plates by design (pocket halves align once the plates sit
next to each other).

### Finger notches

One finger notch per tool pocket, added in the Layout step as described
above (see the consolidated table under "Tool set" for per-tool depth
status). Other than depth, notches were sized and positioned by hand
(drag-resize in Layout) rather than to a fixed rule.

### The singularity issue

Initial STEP/STL exports came out inverted — solid tool-shaped plugs
instead of a tray with recessed pockets — in both ToolTrace's own preview
and in Bambu Studio. `Type` was confirmed still set to `Gridfinity` (ruling
out a Foam-mode mixup). Root cause: a "sketch singularity" (a
self-intersecting loop) in one hand-traced tool outline. Fixed using the
Layout step's **Fine Tune** tool to clean up the offending trace, after
which the export was correct.

### Exports

Final combined 7-tool layout, split into 4 plates, exported as STL (tray +
insert body per plate) plus a `manifest.json`:

- `gridfinity/source/tooltrace/wera-454-7-hf-set-1/split-stl/` — the 4
  plates × {tray, inserts} STL pairs, and `manifest.json` (ToolTrace's own
  piece-position/size metadata). Only the 4 `*-tray.stl` files are actually
  printed (one per plate, one print job at a time in Bambu Studio); the
  `*-inserts.stl` files are not sent to the printer. ToolTrace named this
  export collection `wera-454-hf-6.0x150` internally — that's just the name of one tool in
  the set (it names the collection after a tool, not the whole design) and
  is **not** a dimension of the tray; don't read it as such.
- `gridfinity/source/tooltrace/wera-454-7-hf-set-1/photos/` — the 5 source
  photos (`10mm.jpeg`, `8mm.jpeg`, `6mm.jpeg`, `5mm.jpeg`, `small.jpeg`).
- `gridfinity/source/step/wera-454-7-hf-set-1/wera-454-7-hf-set-1-tray_v1.step`
  — the STEP export of the current, correct combined 7-tool design (whole
  assembly, not split per plate — the plate split only applies to the STL
  print files). This is a parametric/CAD file, unlike the STL meshes above;
  it's the one to reopen in Onshape/FreeCAD if the tray geometry itself
  ever needs editing, rather than just re-slicing.

Stale/superseded artifacts still present from the abandoned DXF/Onshape
route (kept for now, not deleted):

- `gridfinity/source/step/wera-454-7-hf-set-1/wera-454-7-tooltrace-combined_v1.step`
- `gridfinity/source/step/wera-454-7-hf-set-1/wera-454-7-tooltrace-combined_v2-separated.step`

These predate the switch to ToolTrace's native Gridfinity export (and the
singularity fix) and are no longer part of the active workflow. Safe to
remove in a future cleanup pass — don't confuse them with the current
`wera-454-7-hf-set-1-tray_v1.step` above, which is unrelated despite the
similar filenames.

(The stray retrace DXF that was also sitting in
`gridfinity/source/tooltrace/wera-454-7-hf-set-1/` from this same abandoned
route was removed before it was ever committed — not needed.)

---

## Status

- [x] All 7 tools photographed (colored background, distance + zoom,
      shadow-free)
- [x] All 7 tools traced in ToolTrace (Fast mode)
- [x] Combined into one workspace via Import Traces
- [x] Laid out on a 9u × 11u grid, no overlap
- [x] Pocket depths set per tool (70%-of-width rule)
- [x] Finger notches added per tool
- [x] Sketch singularity found and fixed via Fine Tune
- [x] Split for Multiple Prints configured (252×252 mm, 4 plates)
- [x] STEP/STL exported and verified in Bambu Studio
- [x] Source photos and split-STL exports copied into repo
- [x] STEP export of the current design copied into repo
- [ ] Finger notch depth / total print height / base thickness recorded
      (TBD above)
- [ ] Printing in progress (per Craig, as of 2026-09-07)
- [ ] Sliced `.3mf` saved to `gridfinity/3mf/wera-454-7-hf-set-1/`
- [ ] Stale STEP artifacts from the abandoned Onshape route removed
      (`wera-454-7-tooltrace-combined_v1.step`, `_v2-separated.step`)
- [ ] STL archived to `gridfinity/stl/inserts/wera-454-7-hf-set-1/`

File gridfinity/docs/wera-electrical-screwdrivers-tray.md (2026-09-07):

# Wera Kraftform Plus 160i/6 Screwdriver Tray — Design Notes

Gridfinity tray for the Wera Kraftform Plus 160i/6 insulated electrical
screwdriver set, driven by tooltrace.ai STEP profiles imported into Onshape.
Mirrors the workflow in `allen-wrench-tray.md`.

---

## Source Files

`source/step/wera-electrical-screwdrivers/shadowbow.step` is the combined
tooltrace STEP export. Matching STL + DXF reference copies (7 bodies) are in
`source/tooltrace/wera-electrical-screwdrivers/`:

| File | Notes |
|---|---|
| `body_1.stl` – `body_6.stl` | One per screwdriver in the 6-piece set |
| `body_7.stl` | Likely the rack/holder body — confirm |

`wera-electrical-screwdrivers-mm.dxf` is the combined trace.

---

## Onshape Workflow

Same pattern as `allen-wrench-tray.md`:

1. Import STEP, orient flat on the Top Plane.
2. Trace/offset the pocket per screwdriver (start at 0.3 mm clearance).
3. Extrude the Gridfinity tray body and subtract the pockets.
4. Apply the standard Gridfinity bin-bottom interface.
5. Export STL → `gridfinity/stl/inserts/wera-electrical-screwdrivers/`
   (done — see Status below; this copy was recovered from the committed `.3mf`, not re-exported from Onshape).
6. Slice in Bambu Studio → `.3mf` → `gridfinity/3mf/wera-electrical-screwdrivers/`.
7. Add the Onshape link to `gridfinity/source/onshape/links.md`.

---

## Status

- [x] STEP/tooltrace source files added
- [x] Onshape Part Studio created (tray body + pockets)
- [x] Test pocket fit verified
- [x] 3MF sliced and saved → `3mf/wera-electrical-screwdrivers/wera-kraftform-160i-tray_4x6x3.9u_v1.3mf`
- [x] **Printed and installed (2026-09-06)**
- [x] STL archived to `stl/inserts/wera-electrical-screwdrivers/wera-kraftform-160i-tray_4x6x3.9u_v1.stl`
      — recovered 2026-09-06 by extracting the mesh directly out of the already-committed
      `.3mf` (Onshape no longer has this Part Studio). Its internal Bambu metadata calls it
      `body_7.stl` — a leftover filename, not a sign it's the raw tooltrace body — confirmed
      by its bounding box (167.5 × 251.5 mm), which matches a 4×6 Gridfinity footprint exactly.
- [ ] Onshape link added to `links.md`

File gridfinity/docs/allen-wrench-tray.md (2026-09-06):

# Allen Wrench Tray — Design Notes

Gridfinity tray holders for Allen (hex) wrench sets, driven by
tooltrace.ai STEP profiles imported into Onshape.

---

## Source Files

Three STEP files exported from tooltrace.ai are in `source/step/allen-wrenches/`,
with matching STL + DXF reference copies in `source/tooltrace/allen-wrenches/`:

| File | Wrench size | Notes |
|---|---|---|
| `body_1.step` | _(add size)_ | |
| `body_2.step` | _(add size)_ | |
| `body_3.step` | _(add size)_ | |

`colorful-wiha-hex-keys-mm.dxf` is the combined tooltrace trace of the full set.

---

## Onshape Workflow

1. **Import STEP** into Onshape as a new Part Studio or use Insert → Other documents.
2. **Orient** the wrench profile flat on the Top Plane.
3. **Trace the pocket**: create a sketch on the Top Plane, project or manually trace the
   profile outline with an offset (start with 0.3 mm clearance; adjust after test print).
4. **Tray body**: extrude a Gridfinity-sized rectangular block to the target height.
5. **Subtract the pocket**: extrude-remove the traced profile to the required depth.
6. **Gridfinity interface**: apply the standard bin bottom geometry
   (stacking lip, 42 mm grid alignment, optional magnet pockets).
7. **Export STL** → `gridfinity/stl/inserts/allen-wrenches/`
8. **Slice in Bambu Studio** → save `.3mf` → `gridfinity/3mf/allen-wrenches/`
9. **Add Onshape link** to `gridfinity/source/onshape/links.md`

---

## Sizing Notes

Allen wrenches taper significantly along their length. Decide early:

- **Short-arm pocket**: pocket depth matches the short arm; wrench drops straight in.
- **Long-arm pocket**: pocket runs the full long arm; wrench lays flat.
- **Angled slot**: wrench sits at ~15° so the ball-end (if present) clears the rim.

Recommended starting tray size: **2×1** grid units (84 × 42 mm) for a single-row set;
**3×2** for a complete SAE or metric set.

The tray actually built (`wiha-hex-key-tray_4x6x2.1u_sae-metric_v1.stl`) covers both
SAE and metric in one 4×6, 2.1u-tall tray.

---

## Clearance and Fit

| Fit type | Offset from tooltrace profile |
|---|---|
| Loose (drop in) | +0.4 mm |
| Snug (press) | +0.2 mm |
| Reference only | 0 mm |

Test print a single pocket before committing to a full tray.

---

## Naming Convention

Follow `naming.md`:

    allen-wrench-holder_<WxD>x<H>u_<variant>_v<N>.stl

Examples:
- `allen-wrench-holder_2x1x4u_metric_v1.stl`
- `allen-wrench-holder_3x2x4u_sae_v1.stl`

---

## Status

- [x] STEP files added to `source/step/allen-wrenches/`
- [x] Onshape Part Studio created (tray body + pockets)
- [x] Test pocket fit verified
- [x] Full tray STL exported → `stl/inserts/allen-wrenches/wiha-hex-key-tray_4x6x2.1u_sae-metric_v1.stl`
- [x] **Printed and installed (2026-09-06)**
- [ ] 3MF archived to `3mf/allen-wrenches/` — confirmed (2026-09-06, via `git log --all`)
      this file was never committed on any branch. Nothing design-wise is lost: the STL that
      was sliced (`stl/inserts/allen-wrenches/wiha-hex-key-tray_4x6x2.1u_sae-metric_v1.stl`)
      is already here — re-slice it in Bambu Studio (check recent projects first if you want
      the original plate/print settings) and save the `.3mf` here.
- [ ] Onshape link added to `links.md`

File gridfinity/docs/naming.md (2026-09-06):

# Naming convention

    <name>_<WxD>x<height-u>u_<variant>_v<major>[.<minor>].<ext>

Applies to every exported file — `.stl`, `.3mf`, `.step`/`.stp` — not just STL.

- `W` and `D` are Gridfinity grid units (1 unit = 42 mm)
- `height-u` is height in Gridfinity height units (7 mm per unit)
- `variant` describes fit or subtype (e.g. `magnet`, `loose`, `snug`, `sae`, `metric`)
- Version suffix: `_v1`, `_v2`, or `_v1.1` for a minor revision

Examples:
- `baseplate_4x4x0u_magnet_v1.stl`
- `calipers-holder_2x1x6u_loose_v1.1.stl`
- `wera-kraftform-160i-tray_4x6x3.9u_v1.3mf`

General rules (see `../../docs/repo-conventions.md` for the repo-wide version):
- Lowercase filenames
- Hyphens for multi-word descriptors
- Version suffix on every exported file

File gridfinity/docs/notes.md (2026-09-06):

# Gridfinity Notes

Project-specific design notes, fit observations, and print decisions.

## Clearance reference

See `allen-wrench-tray.md` for the clearance table used on tooltrace-derived
pockets (loose / snug / reference-only). Reuse those offsets as a starting
point for new tools before test-printing a single pocket.

## Nystrom Performance cabinet trays (`3mf/nystrom_performance/`)

`tray-1` through `tray-9` and `left-hand-drill-tray` are built but their
contents aren't recorded yet. Fill in as each tray is confirmed:

| File | Contents |
|---|---|
| `tray-1_v1.3mf` | _(TBD)_ |
| `tray-2_v1.3mf` | _(TBD)_ |
| `tray-3_v1.3mf` | _(TBD)_ |
| `tray-4_v1.3mf` | _(TBD)_ |
| `tray-5_v1.3mf` | _(TBD)_ |
| `tray-6_v1.3mf` | _(TBD)_ |
| `tray-7_v1.3mf` | _(TBD)_ |
| `tray-8_v1.3mf` | _(TBD)_ |
| `tray-9_v1.3mf` | _(TBD)_ |
| `left-hand-drill-tray_v1.3mf` | Left-hand drill bits |

## Baseplates (`3mf/baseplates/magnet/`, `stl/baseplates/magnet/`)

| File | Notes |
|---|---|
| `base_frame_mag_frame_6x6_v1.3mf` | 6×6 magnet baseplate |
| `base_frame_mag_frame_1x6_upper-drawer-x-expansion_v2_gcode.3mf` | 1×6 expansion baseplate, +10 mm X offset for a non-square drawer |

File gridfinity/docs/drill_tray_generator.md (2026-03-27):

# Parametric Drill Bit Tray Generator (Onshape)

This document describes how to build a **parametric drill-bit tray
generator** in Onshape.\
The goal is a single Part Studio that can generate trays for multiple
drill sets such as:

-   fractional
-   letter
-   number
-   metric
-   left-hand

The model should allow easy changes to tray size, hole spacing, and
drill diameters.

------------------------------------------------------------------------

# Design Goals

The generator should allow control over:

-   tray size (Gridfinity or custom drawer)
-   number of holes
-   hole diameters
-   hole spacing
-   labels
-   margins and walls

------------------------------------------------------------------------

# Step 1 --- Create Variables

At the top of the Part Studio create variables.

Example:

    #tray_width
    #tray_depth
    #tray_height = 12 mm

    #margin = 3 mm
    #row_spacing = 12 mm
    #column_spacing = 12 mm

    #hole_depth = 10 mm
    #wall_thickness = 1.6 mm

For Gridfinity compatibility:

    #grid = 42 mm
    #tray_width = 3 * #grid
    #tray_depth = 2 * #grid

------------------------------------------------------------------------

# Step 2 --- Tray Body

Create **Sketch 1 on the Top Plane**.

Draw a rectangle:

    width = #tray_width
    height = #tray_depth

Extrude the sketch:

    height = #tray_height

You now have the tray body.

------------------------------------------------------------------------

# Step 3 --- Pocket the Tray

Create a sketch on the **top face**.

Offset the outer rectangle:

    offset = #wall_thickness

Extrude remove:

    depth = #tray_height - 2 mm

This creates the interior tray pocket.

------------------------------------------------------------------------

# Step 4 --- Hole Pattern Layout

Create a sketch on the **tray floor**.

Place the first hole center:

    x = #margin
    y = #margin

Define spacing:

    horizontal spacing = #column_spacing
    vertical spacing = #row_spacing

------------------------------------------------------------------------

# Step 5 --- Hole Feature

Use the **Hole Tool** rather than extrude.

    diameter = configured
    depth = #hole_depth

Later this diameter will be controlled by configurations.

------------------------------------------------------------------------

# Step 6 --- Linear Pattern

Pattern the hole feature.

    columns = variable
    rows = variable
    spacing = #column_spacing / #row_spacing

This creates a grid of holes.

------------------------------------------------------------------------

# Step 7 --- Label Sketch

Create text labels near each hole.

Example:

    1/16
    3/32
    1/8
    5/32

Extrude remove:

    depth = 0.4 mm

This engraves the labels.

------------------------------------------------------------------------

# Step 8 --- Fillets

Add comfort edges:

    top edge fillet = 1 mm
    hole chamfer = 0.5 mm

------------------------------------------------------------------------

# Step 9 --- Configurations

Create configuration options such as:

    drill_set = fractional | letter | number | metric

Each configuration controls:

-   hole diameters
-   number of holes
-   label text

Example:

  Set          Holes
  ------------ ----------
  Fractional   29
  Letter       26
  Number       80
  Metric       variable

------------------------------------------------------------------------

# Step 10 --- Export Workflow

For each configuration:

1.  Right-click the part
2.  Export STL

Then create plate layouts in your slicer (for example Bambu Studio) and
save them as `.3mf`.

------------------------------------------------------------------------

# Recommended Feature Order

Your Onshape feature tree should look like:

    Variables
    Sketch: tray footprint
    Extrude: tray body
    Sketch: pocket
    Extrude remove
    Sketch: hole layout
    Hole feature
    Linear pattern
    Sketch: labels
    Extrude remove
    Fillets
    Configurations

Keeping the feature tree clean makes future edits much easier.

------------------------------------------------------------------------

# Possible Future Improvements

Instead of fixed hole sizes, hole diameters can be driven from a table
of drill sizes.

Example fractional set:

    1/16
    5/64
    3/32
    7/64
    1/8
    ...
    1/2

This allows a single model to generate multiple tray variants
automatically.

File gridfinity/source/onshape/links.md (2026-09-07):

# Onshape Links

Add document URLs and version/export notes here.

---

## Allen Wrench Tray

| Document | URL | Notes |
|---|-----|---|
| _(add name)_ | _(add URL)_ | |

---

## Drill Bit Trays (Nystrom Performance)

| Document | URL | Notes |
|---|-----|---|
| _(add name)_ | _(add URL)_ | |

---

## Wera 454/7 HF Set 1 Tray

| Document | URL | Notes |
|---|-----|---|
| Wera 454-7 HF Set 1 Tray | https://cad.onshape.com/documents/e3d2663aa007421ab93823e3/w/04d6597c6283cc488d0a575c/e/c9e9925d189f10ceaff34c0d | Created 2026-09-06; public document (Free Onshape plan). STEP import + nest not yet done. |

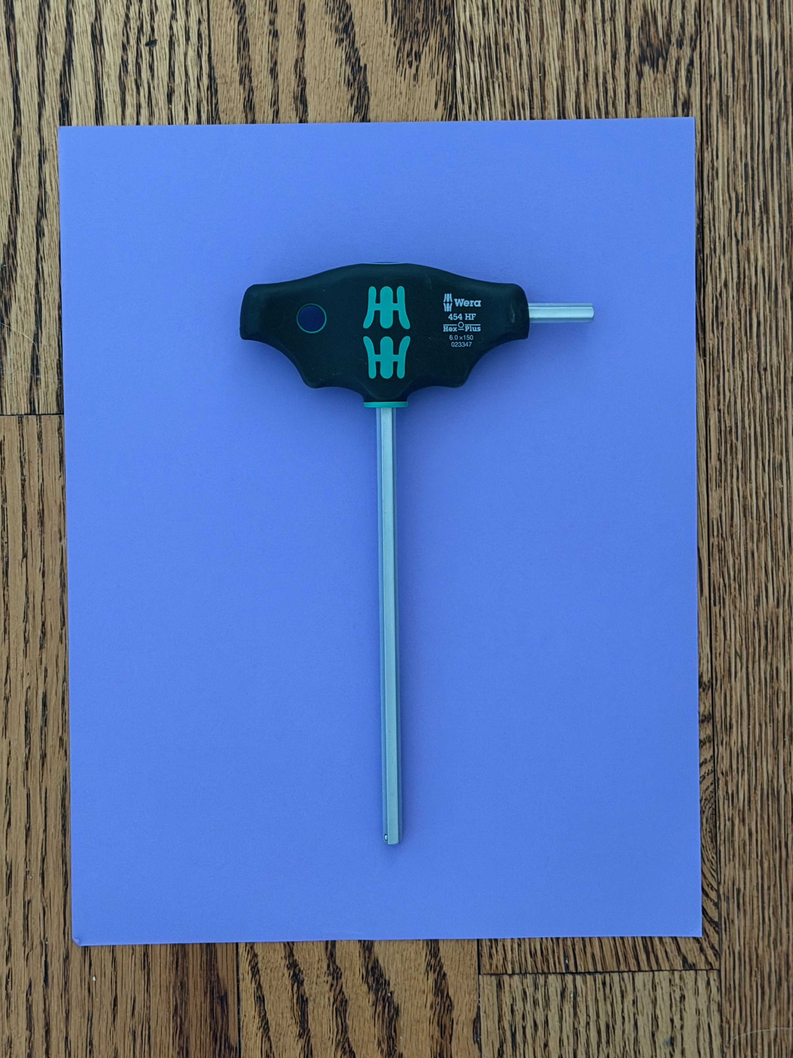
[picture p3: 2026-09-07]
gridfinity/source/tooltrace/wera-454-7-hf-set-1/photos/6mm.jpeg

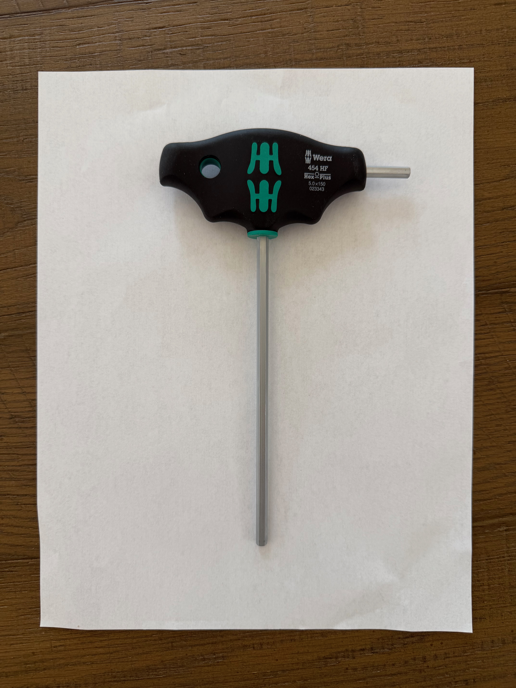
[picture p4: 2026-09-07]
gridfinity/source/tooltrace/wera-454-7-hf-set-1/photos/5mm.jpeg

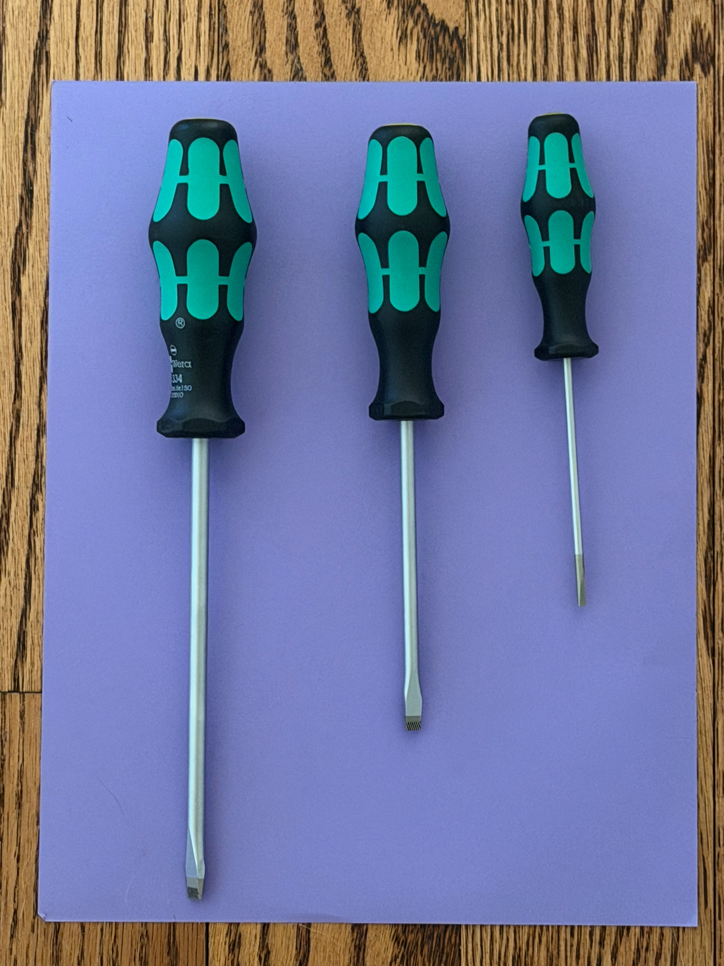
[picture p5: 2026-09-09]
gridfinity/source/tooltrace/wera-phillips-flathead-screwdrivers/photos/flathead.jpeg

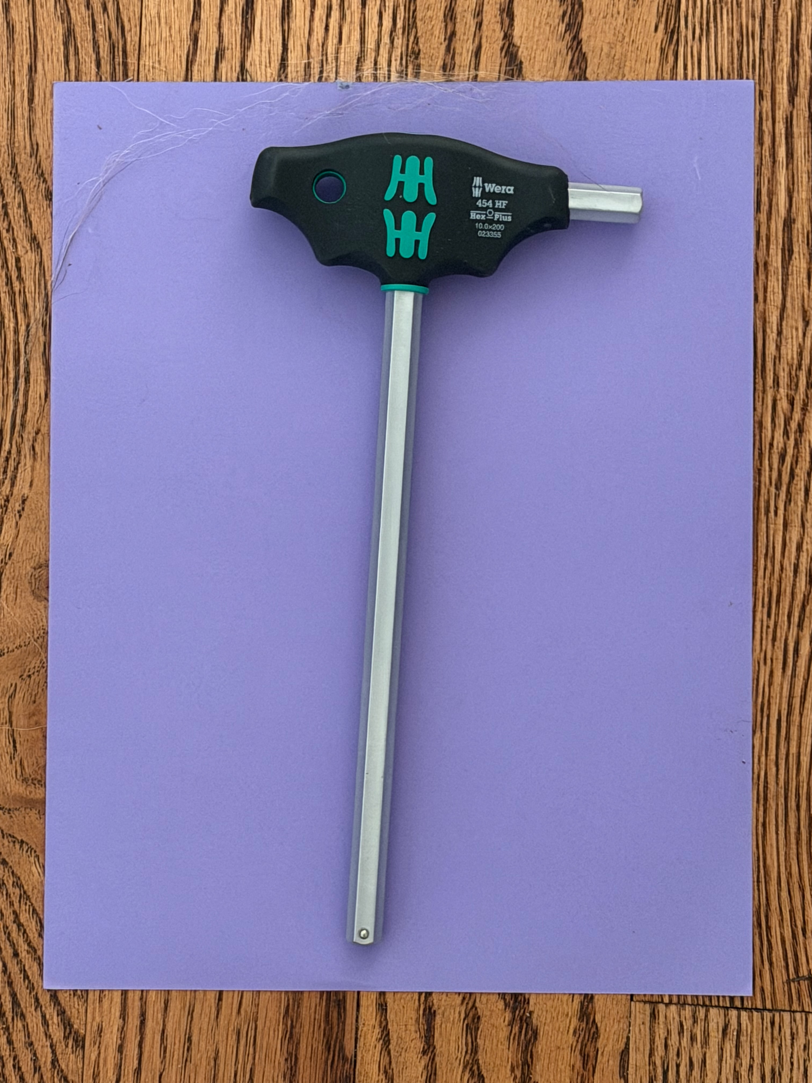
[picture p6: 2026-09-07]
gridfinity/source/tooltrace/wera-454-7-hf-set-1/photos/10mm.jpeg

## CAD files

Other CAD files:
gridfinity/3mf/baseplates/magnet/base_frame_mag_frame_1x6_upper-drawer-x-expansion_v2_gcode.3mf
gridfinity/3mf/nystrom_performance/tray-9_v1.3mf
gridfinity/3mf/wera-367-6-torx/wera-367-6-torx-tray_7x9x5.6u_v1.3mf
gridfinity/source/step/allen-wrenches/body_2.step
gridfinity/source/step/wera-367-6-torx/wera-367-6-torx-tray_v1.step
gridfinity/source/step/wera-454-7-hf-set-1/wera-454-7-tooltrace-combined_v1.step
gridfinity/source/tooltrace/allen-wrenches/body_2.stl
gridfinity/source/tooltrace/wera-454-7-hf-set-1/split-stl/wera-454-hf-6.0x150-piece-4-of-4-tray.stl
gridfinity/stl/inserts/allen-wrenches/wiha-hex-key-tray_4x6x2.1u_sae-metric_v1.stl
gridfinity/stl/inserts/wera-367-6-torx/wera-367-6-torx-tray_2.5x1.5x5.6u_piece3-of-4_v1.stl
gridfinity/3mf/baseplates/magnet/base_frame_mag_frame_6x6_v1.3mf
gridfinity/3mf/nystrom_performance/tray-5_v1.3mf
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

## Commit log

2026-01-21 Initialize Gridfinity STL library structure
2026-01-22 Track STL files with Git LFS
2026-01-22 Add base_frame mag_frame baseplates (v1)
    [base_frame_mag_frame_1x3_upper-drawer-corner_v1.stl, base_frame_mag_frame_1x6_upper-drawer-x-expansion_v1.stl, base_frame_mag_frame_5x3_lower-drawer-corner_v1.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]
2026-01-29 Updated 6x3 frame to accommodate un-square drawer shape.
    [base_frame_mag_frame-6x3_y-expansion-both-drawers-v2.stl, base_frame_mag_frame_6x6_v1.3mf]
2026-02-09 Updated: 6 x 1 grid with +10mm offset (top drawer only)
    [base_frame_mag_frame_1x6_upper_drawer-x-sxpansion_v2.stl, stl:base:baseplates:magnet:base_frame_mag_frame_1x6_upper_drawer-x-sxpansion_v2.stl.gcode.3mf]
2026-02-11 Updated 5x3 and 5x6 expansion grids for workbench
    [base_frame_mag_frame_5x3_lower-drawer-corner_v2.stl, base_frame_mag_frame_5x3_lower-drawer-corner_v3.stl, base_frame_mag_frame_5x6_lower-drawer-x-expansion_v2.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]
2026-03-26 Initialize cad repo
2026-03-27 Update README for general CAD repository
    [Left hand drill tray.3mf, Tray 1.3mf, Tray 2.3mf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]
2026-03-27 Restructure CAD repo to project-first layout
    [Left hand drill tray.3mf, Tray 1.3mf, Tray 2.3mf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]
2026-03-27 Update README to reflect project-first CAD repo structure
2026-03-27 Add Onshape drill tray generator design guide
2026-05-25 Add tooltrace STEP profiles for allen wrench holders
    [body_1.step, body_2.step, body_3.step]
2026-05-25 Add Wiha hex key tray STL (4x6, 2.1u, SAE+metric)
    [wiha-hex-key-tray_4x6x2.1u_sae-metric_v1.stl]
2026-05-25 Add Wera Kraftform 160i/6 tray (4x6, 3.9u); add tooltrace source STLs for allen wrenches and wera
    [body_1.stl, body_2.stl, body_3.stl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]
2026-05-25 Add STEP and DXF source files for Wera 160i/6 and Wiha hex keys
    [colorful-wiha-hex-keys-mm.dxf, shadowbow.step, wera-electrical-screwdrivers-mm.dxf]
2026-05-25 Update CLAUDE.md: current repo state, tooltrace workflow, git constraint
2026-07-15 Add Bambu Studio tool tray print profile with minimal filament settings
2026-09-06 Reorganize repo docs, flatten stl/ layout, fix missing DXF LFS rule
2026-09-06 Mark Wiha and Wera trays as printed and installed
2026-09-06 Track DXF tracing files via Git LFS going forward
    [colorful-wiha-hex-keys-mm.dxf, wera-electrical-screwdrivers-mm.dxf]
2026-09-06 Recover Wera tray STL from committed 3mf; update tray docs
    [wera-kraftform-160i-tray_4x6x3.9u_v1.stl]
2026-09-06 Replace print profile with Bambu-Studio-verified version; ignore Claude outputs/
2026-09-06 Add Wera 454/7 HF Set 1 tray project notes and reusable ToolTrace->Onshape workflow doc
    Documents tool dimensions, ToolTrace session/import-traces workflow, STEP
    export gotchas (HEIC unsupported, auto-generated baseplate solid, shadow
    artifacts in traced outlines), and the plan for Onshape nesting across a
    6x6-grid-unit plate cap. Onshape document created; STEP import and nest
    still pending.
    [wera-454-7-tooltrace-combined_v1.step, wera-454-7-tooltrace-combined_v2-separated.step]
2026-09-07 Add Wera 454/7 HF Set 1 ToolTrace-native source files and rewrite tray doc
    Capture source photos, final split-print STL exports, and the STEP
    export of the current combined design; rewrite the design-notes doc
    to reflect the ToolTrace-native Gridfinity workflow and consolidate
    all per-tool data into one table.
    Claude-Session: https://claude.ai/code/session_016nucMg14BptG8cQUMQB3bF
    [wera-454-7-hf-set-1-tray_v1.step, wera-454-hf-6.0x150-piece-1-of-4-inserts.stl, wera-454-hf-6.0x150-piece-1-of-4-tray.stl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]
2026-09-07 Scaffold Wera flathead + Phillips screwdriver tray projects
    Two separate trays (by design, printed in distinct colors) for the
    same overall tool collection: 3 slotted screwdrivers and 4 Phillips
    screwdrivers. Adds starter docs and empty source folders following
    the existing per-tray convention, and updates CLAUDE.md's repo map.
    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
2026-09-07 Consolidate flathead+Phillips into one combined tray project
    Turned out to be one ToolTrace design (7 tools, 13x3 grid, 3 print
    plates) rather than two separate ones as originally scaffolded, so
    replace the two empty stub projects with a single one matching the
    actual design. Capture the print plan: since flathead and Phillips
    tools are interleaved across plates rather than grouped, color-coding
    happens by printing each plate's insert sheet twice (once per color)
    and hand-sorting pieces by tool-head shape, rather than printing
    whole plates in different colors.
    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
    [wera-phillips-flathead-piece-1-of-3-inserts.stl, wera-phillips-flathead-piece-1-of-3-tray.stl, wera-phillips-flathead-piece-2-of-3-inserts.stl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]
2026-09-09 Archive Wera phillips+flathead tray 3MF and STL; drop insert plan
    Trays printed and archived (3 plates, single color). Dropped the
    color-coded insert plan — the exported insert STLs bundle each tool's
    plug at its real pocket depth rather than reset to sit flat on a print
    bed, and the trays are usable without them, so not worth the extra
    Bambu Studio mesh-splitting work.
    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
    [wera-phillips-flathead-tray_4.33x3x5.6u_piece1-of-3_v1.stl, wera-phillips-flathead-tray_4.33x3x5.6u_piece2-of-3_v1.stl, wera-phillips-flathead-tray_4.33x3x5.6u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]
2026-09-09 Scaffold Wera 367/6 TORX tray project
    New project after the flathead+Phillips tray merged to main. Adds a
    starter doc with the catalog tool set (needs confirming against the
    physical set — Wera also sells a similar 7-piece HF variant) and
    empty source folders following the existing per-tray convention.
    Updates CLAUDE.md's repo map, active branch, and project status
    (also marks the flathead+Phillips tray printed and archived).
    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
2026-09-09 Add Wera 367/6 TORX ToolTrace exports; record layout and pocket depths
    STEP and 4-plate split-STL exports for the combined 6-tool design
    (7x9 grid). Doc now has per-tool pocket depths (handle-diameter x
    70% rule) and finger notch depths, plus the layout/plate breakdown.
    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
    [green-handled-screwdrivers-piece-1-of-4-inserts.stl, green-handled-screwdrivers-piece-1-of-4-tray.stl, green-handled-screwdrivers-piece-2-of-4-inserts.stl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]
2026-09-10 Archive Wera 367/6 TORX tray STL and 3MF; complete status checklist
    All 4 tray STLs renamed and archived to stl/inserts/, sliced Bambu
    Studio project archived to 3mf/. Doc status checklist now reflects
    what actually happened this session (tracing, layout, pocket depths,
    finger notches, singularity fix, print) rather than sitting stale.
    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
    [wera-367-6-torx-tray_2.5x1.5x5.6u_piece3-of-4_v1.stl, wera-367-6-torx-tray_2.5x4.5x5.6u_piece1-of-4_v1.stl, wera-367-6-torx-tray_2.5x4.5x5.6u_piece2-of-4_v1.st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]
